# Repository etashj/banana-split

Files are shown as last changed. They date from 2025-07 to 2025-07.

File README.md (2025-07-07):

# banana split
A split, tented keyboard with columnar staggering. Designed from scratch with ergogen, KiCad, and Fusion 360, and fully open-source. 
Runs on 18650 batteries (3.7V 1200 mAh) which provide a mass for tenting. Plan to use a clear acrylic sandwich case which. 
Design will feature clear case, white keys, brown modifiers, and yellow home "row" for a banana split. 40 keys with 4 layer cusotmizable layout. 
Uses 2 nice!nano and nice!view boards which show status. 

Making this because there arent really many ergonomic, but compact keybaord for large hand (almost oxymoronic) which also feature mechanical switches. 

More Photos/CAD model coming soon :/
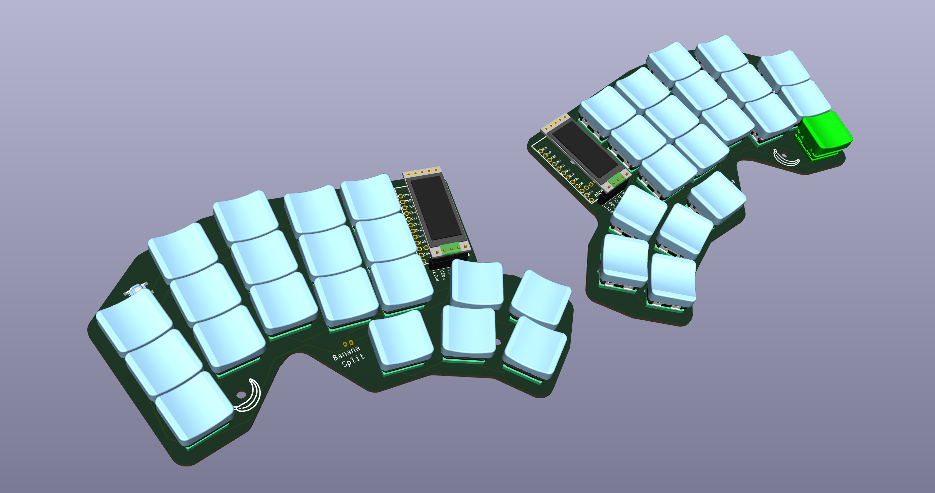
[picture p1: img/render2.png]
render 2


### Case & Keycaps
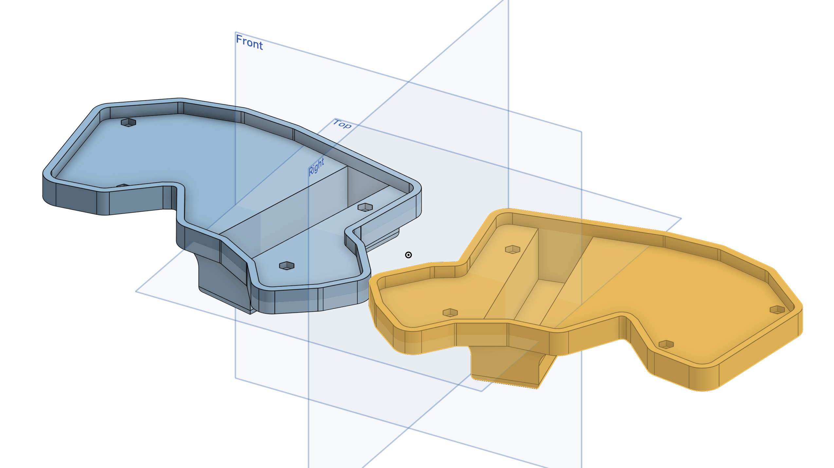
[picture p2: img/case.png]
case

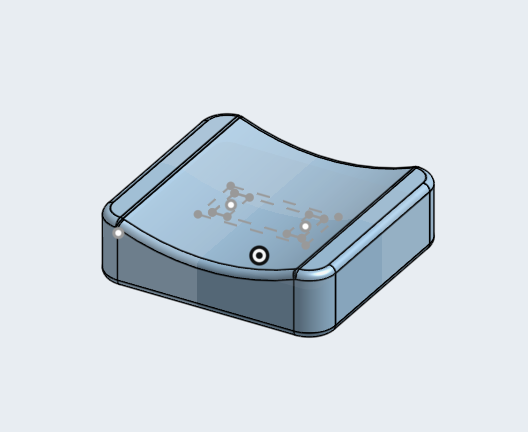
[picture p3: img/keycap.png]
keycap

### PCB
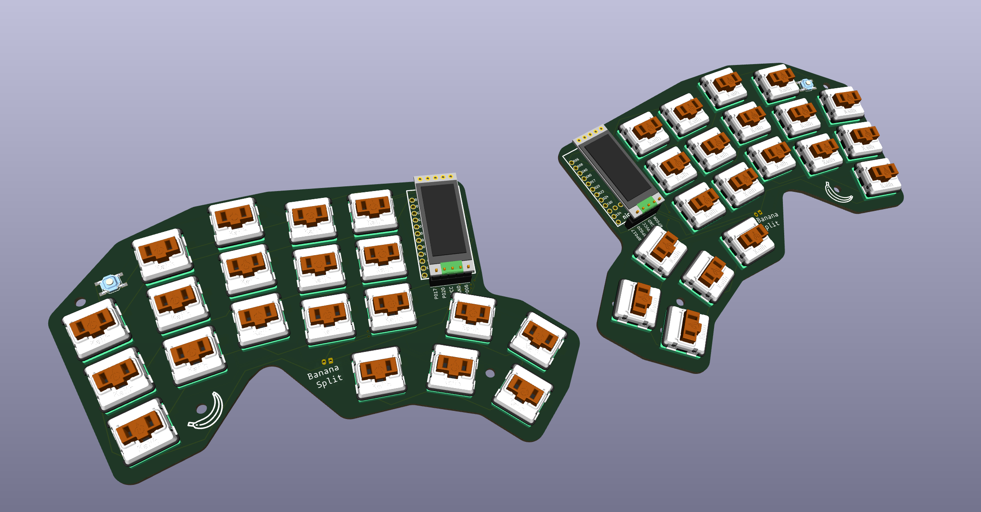
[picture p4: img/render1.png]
render 1 july 7

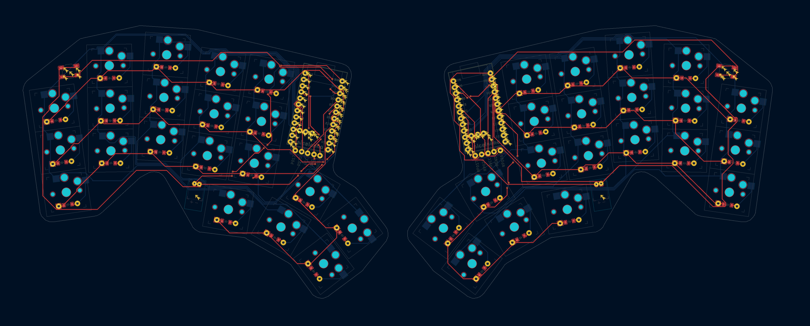
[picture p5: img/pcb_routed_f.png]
PCB Routed Front

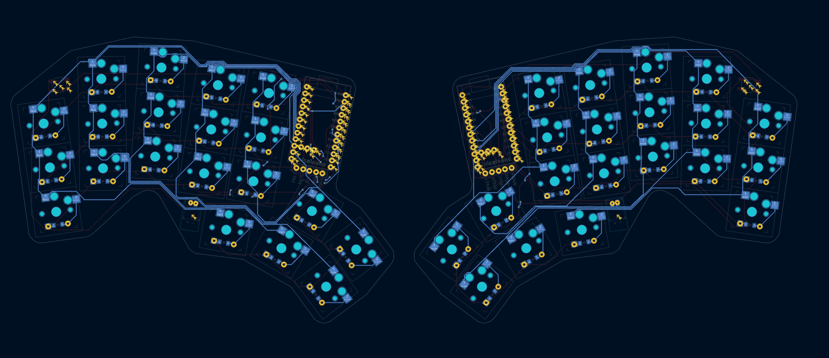
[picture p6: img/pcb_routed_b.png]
PCB Routed Back

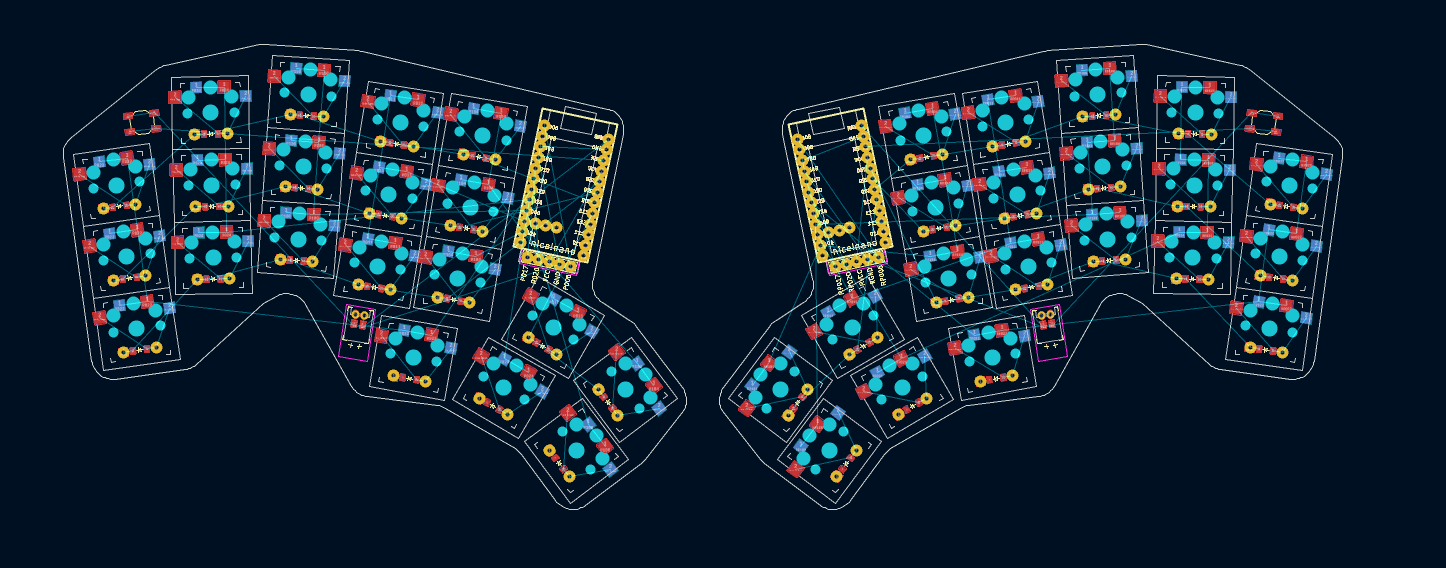
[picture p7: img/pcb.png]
PCB

### ErgoPad Layout
[Design your own at this link](https://pashutk.com/ergopad/)
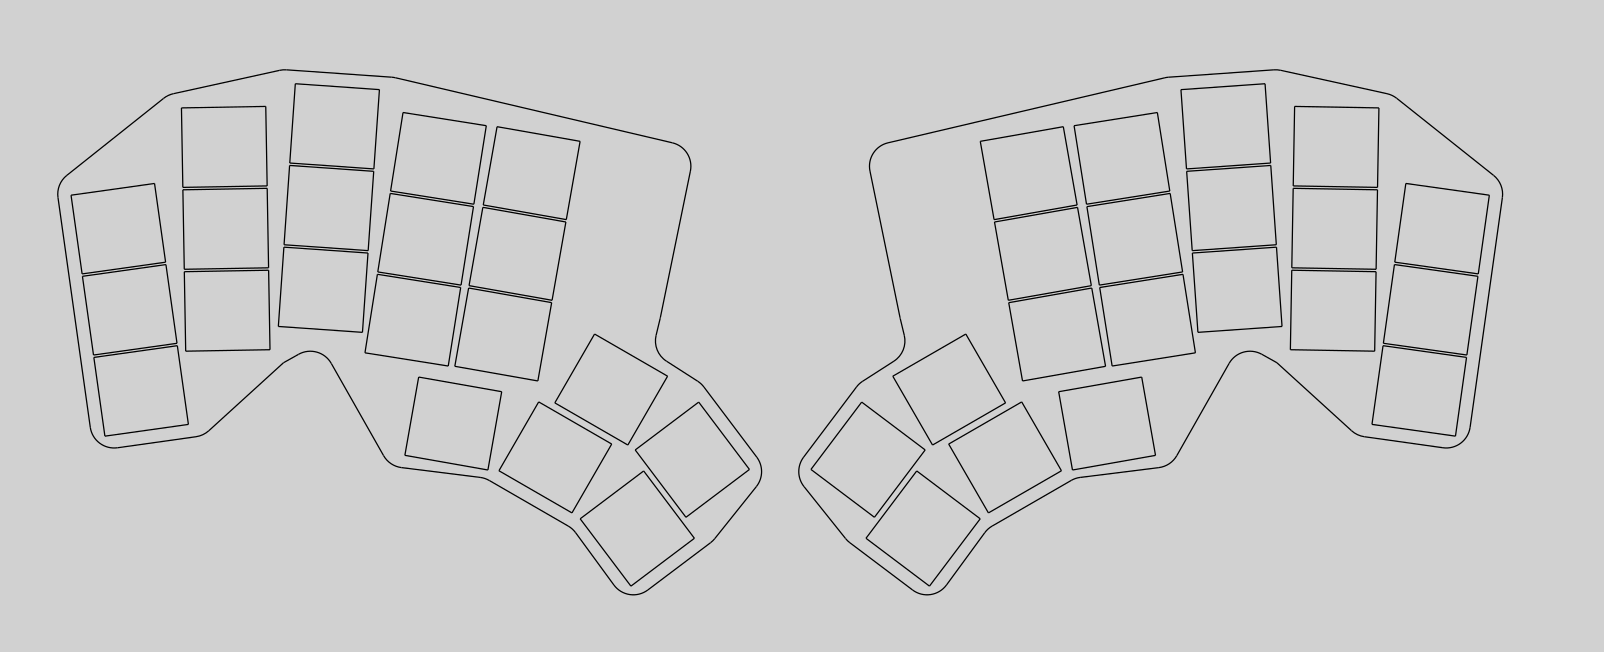
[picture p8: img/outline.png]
Ergopad w/ Outline


Features: 
 - Low profile mechanical switches
 - Low profile sculpted keycaps
 - Wireless! Uses 2 nice!nano (I think)
 - Small display for status info and idle image (2 nice!view)
 - Small/durable 3D printed case
 - Hot swappable switches
 - Reaosnably large battery
 - Easy to switch between the onboard MBP keyboard and good macOS compatibility. (this is a layout consderation). 
 - Small-ish/Portable (Ideally msaller than a handheld console like the Swithc so the case can be used)
 - Customaized for my (larger) hands
 - Fewer keycaps (less movement)

 ### Bill of Materials

| Part Name | Source | Qt | Unit Price | Price | Note |
|-----|-----|---|---|---|---|
|PCB|JLCPCB|5|3.28|16.4|min 5|
|Clear Case|JLC3DP|1|30.64|30.64||
|Keycaps|JLC3DP|40|0.3|12||
|Nice!Nano|[Typeractive](https://typeractive.xyz/products/nice-nano)|2|25|50||
|Nice!View|[Typeractive](https://typeractive.xyz/products/nice-view)|2|20|40||
|Twilight Silent Kalih Choc V1|[BeeKeeb](https://shop.beekeeb.com/product/kailh-silent-switch-linear-twilight/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)|40|1.05|42||
|Choc V1 HotSwap Sockets 100pc |[AliExpress](https://www.aliexpress.us/item/3256808288570508.html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)|1|7.40|7.40|Best price is at 100 pc|
|M3 Screw and Nut Set|[AliExpress](https://www.aliexpress.us/item/3256807407760967.html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)|1|3.94|3.94||
|Rubber Feet 4pk|[AliExpress](https://www.aliexpress.us/item/3256809073816688.html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,scm-url:1007.40050.354490.0,pvid:52a5a5e8-bf4b-41b6-8108-8eef565778c2,tpp_buckets:668%232846%238111%231996&pdp_ext_f=%7B%22order%22%3A%221%22%2C%22eval%22%3A%221%22%2C%22sceneId%22%3A%2230050%22%7D&pdp_npi=4%40dis%21USD%210.91%210.73%21%21%210.91%210.73%21%402103244817519174567381591e3a81%2112000048590082109%21rec%21US%21%21ABX&utparam-url=scene%3ApcDetailTopMoreOtherSeller%7Cquery_from%3A)|2|0.91|1.82||
|18650 Battery Holder|[AliExpress](https://www.aliexpress.us/item/3256802855487110.html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)|2|1.16|2.32||
|18650 Cell|[LIION Wholesale](https://liionwholesale.com/products/vapcell-k25-18650-20a-35a-flat-top-2500mah-battery-genuine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)|2|3.49|6.98||
|Surface Mount Push Switch|[SparkFun](https://liionwholesale.com/products/vapcell-k25-18650-20a-35a-flat-top-2500mah-battery-genuine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)|2|1.05|2.1||

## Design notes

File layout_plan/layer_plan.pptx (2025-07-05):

## Home Layer

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
enter

n

?
/

Ctrl

Shift

Cmd

BackSp

Space

Opt

Symbols

Num + Nav

When pressed together forms Funcs

## Num + Nav Layer

7

8

9

null

null

home

Left

backsp

Up

End

Right
→

del

esc

4

5

6

null

null

Down

PgUp

null

1

2

null

enter

null

0

3

Tab

enter

null

PgDn

Ctrl

Shift

Cmd

BackSp

Space

Opt

Symbols

Num + Nav

When pressed together forms Funcs

## Symbol Layer

%

$

null

null

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
enter

*

?

Ctrl

Shift

Cmd

BackSp

Space

Opt

Symbols

Num + Nav

When pressed together forms Funcs

## Func Layer

F7

F8

F9

null

null

Br-

Br+

Screenshot

F10

F4

F5

F6

null

null

<<

pause

>>

Emoji Panel

F11

F1

F2

F3

null

null

Vol-

Mute

Vol+

null

F12

Tab

enter

Lock Device

Ctrl

Shift

Cmd

BackSp

Space

Opt

Symbols

Num + Nav

When pressed together forms Funcs

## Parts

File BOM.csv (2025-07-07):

Banana Split Bill of Materials
 | Part Name | Source (linked) | Quantity | Unit Price | Price | Notes
Manufactured Parts
 | PCB | JLCPCB | 5 | $3.28 | $16.40 | Minimum 5 Produced
 | Clear Case | JLC3DP | 1 | $30.64 | $30.64
Keycaps | Translucent Keycaps | JLC3DP | 22 | $0.30 | $6.60
 | Translucent Yellow Keycaps | JLC3DP | 10 | $0.30 | $3.00
 | Translucent Brown Keycaps | JLC3DP | 8 | $0.30 | $2.40
Purchased Components
 | Nice!Nano | Typeractive | 2 | $25.00 | $50.00
 | Nice!View | Typeractive | 2 | $20.00 | $40.00
 | 18650 Battery Holder | AliExpress | 2 | $1.16 | $2.32
 | 18650 Battery (VAPCELL K25 18650) | LIION Wholesale | 2 | $3.49 | $6.98
 | Twilight Silent Kalih Choc V1 Switches | BeeKeeb | 40 | $1.05 | $42.00
 | Choc V1 Hot Swap Sockets (100 pc) | AliExpress | 1 | $7.40 | $7.40 | Best price has 100 pc, only use 40.
 | Surface Mount Push Switch (SW_TACT_ALPS_SKQGABE010) | Sparkfun | 2 | $1.05 | $2.10
 | M3 Screw and Nut Set | AliExpress | 1 | $3.94 | $3.94
 | Rubber Feet (4 pack) | AliExpress | 2 | $0.91 | $1.82
SUBTOTAL |  |  |  |  | $215.60
Shipping Estimate |  |  |  |  | $20.00
Projected 7% Tax |  |  |  |  | $16.49
TOTAL |  |  |  |  | $252.09

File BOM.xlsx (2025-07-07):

Banana Split Bill of Materials
 | Part Name | Source (linked) | Quantity | Unit Price | Price | Notes
Manufactured Parts
 | PCB | JLCPCB | 5 | $3.28 | $16.40 | Minimum 5 Produced
 | Clear Case | JLC3DP | 1 | $30.64 | $30.64
Keycaps | Translucent Keycaps | JLC3DP | 22 | $0.30 | $6.60
 | Translucent Yellow Keycaps | JLC3DP | 10 | $0.30 | $3.00
 | Translucent Brown Keycaps | JLC3DP | 8 | $0.30 | $2.40
Purchased Components
 | Nice!Nano | Typeractive (https://typeractive.xyz/products/nice-nano) | 2 | $25.00 | $50.00
 | Nice!View | Typeractive (https://typeractive.xyz/products/nice-view) | 2 | $20.00 | $40.00
 | 18650 Battery Holder | AliExpress (https://www.aliexpress.us/item/3256802855487110.html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) | 2 | $1.16 | $2.32
 | 18650 Battery (VAPCELL K25 18650) | LIION Wholesale (https://liionwholesale.com/products/vapcell-k25-18650-20a-35a-flat-top-2500mah-battery-genuine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) | 2 | $3.49 | $6.98
 | Twilight Silent Kalih Choc V1 Switches | BeeKeeb (https://shop.beekeeb.com/product/kailh-silent-switch-linear-twilight/) | 40 | $1.05 | $42.00
 | Choc V1 Hot Swap Sockets (100 pc) | AliExpress (https://www.aliexpress.us/item/3256808288570508.html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) | 1 | $7.40 | $7.40 | Best price has 100 pc, only use 40.
 | Surface Mount Push Switch (SW_TACT_ALPS_SKQGABE010) | Sparkfun (https://www.sparkfun.com/mini-pushbutton-switch-smd.html) | 2 | $1.05 | $2.10
 | M3 Screw and Nut Set | AliExpress (https://www.aliexpress.us/item/3256807407760967.html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) | 1 | $3.94 | $3.94
 | Rubber Feet (4 pack) | AliExpress (https://www.aliexpress.us/item/3256809073816688.html?scm_id=1007.40050.354490.0&scm-url=1007.40050.354490.0) | 2 | $0.91 | $1.82
SUBTOTAL |  |  |  |  | $215.60
Shipping Estimate |  |  |  |  | $20.00
Projected 7% Tax |  |  |  |  | $16.49
TOTAL |  |  |  |  | $252.09

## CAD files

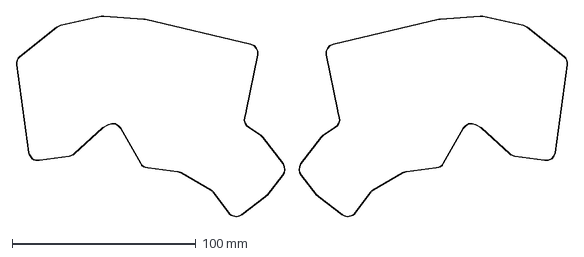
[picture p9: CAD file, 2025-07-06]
ergogen-out/outlines/board_full.dxf
300.3 x 109.1 mm

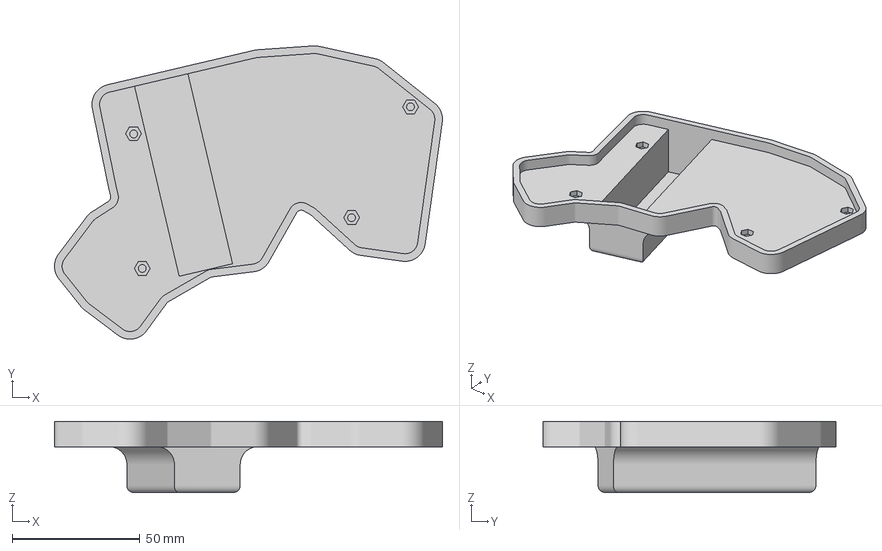
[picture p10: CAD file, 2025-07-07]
case_files/Case-Right.3mf
152.1 x 115.0 x 28.0 mm

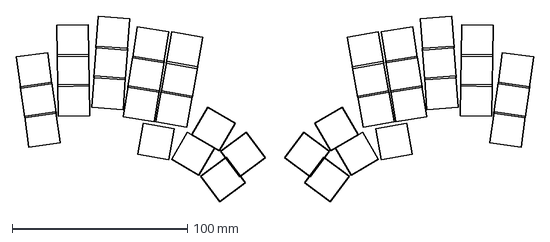
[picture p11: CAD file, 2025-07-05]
ergogen-out/points/demo.dxf
295.1 x 105.7 mm

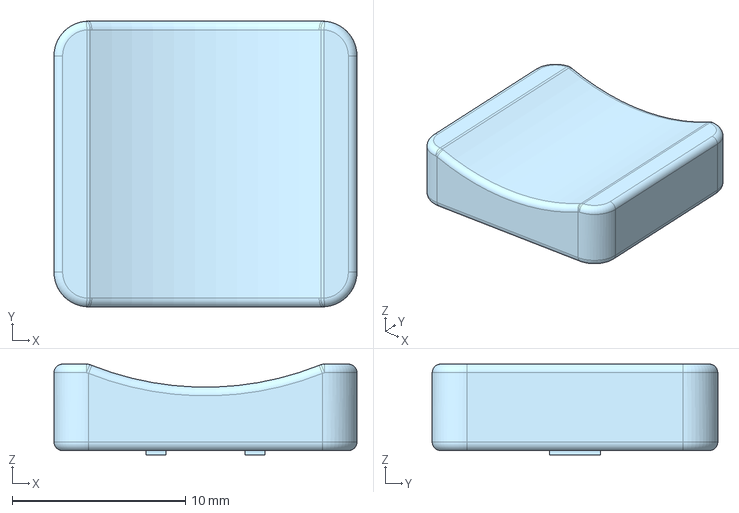
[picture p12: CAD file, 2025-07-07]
models/keycap.step
17.5 x 16.5 x 5.25 mm

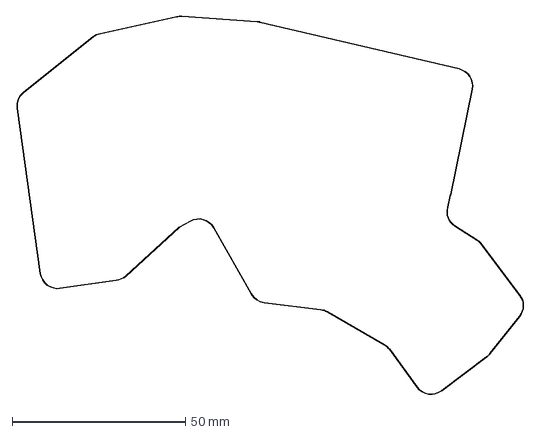
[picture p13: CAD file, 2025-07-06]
ergogen-out/outlines/board_left.dxf
146.6 x 109.1 mm

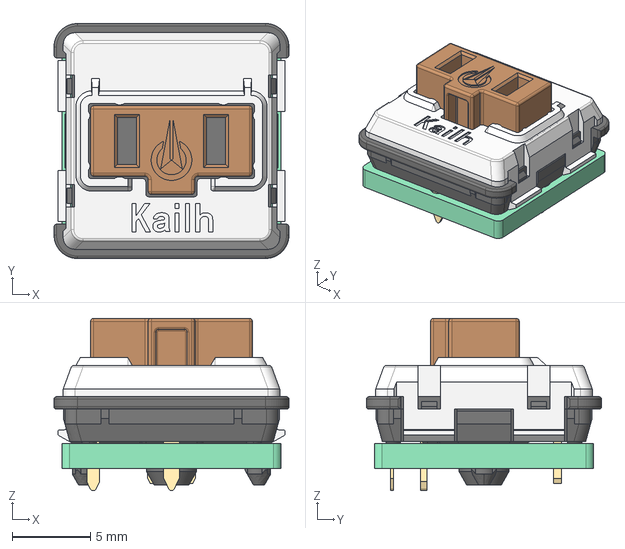
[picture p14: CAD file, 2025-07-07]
models/Kailh_Choc_Low_Profile_Switch.step
15.0 x 15.0 x 11.0 mm

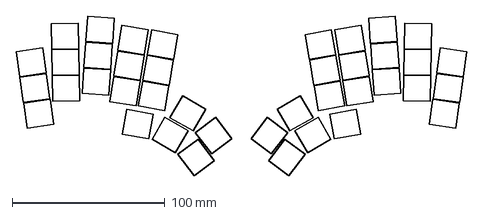
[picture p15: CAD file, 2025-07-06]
ergogen-out/outlines/keys.dxf
294.4 x 104.3 mm

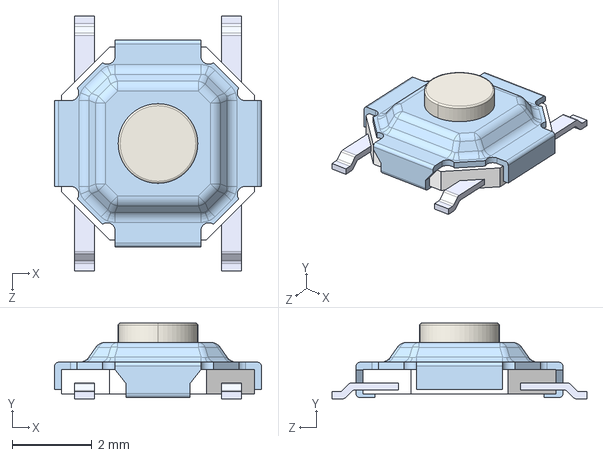
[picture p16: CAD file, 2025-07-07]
models/reset.step
5.20 x 1.90 x 6.40 mm

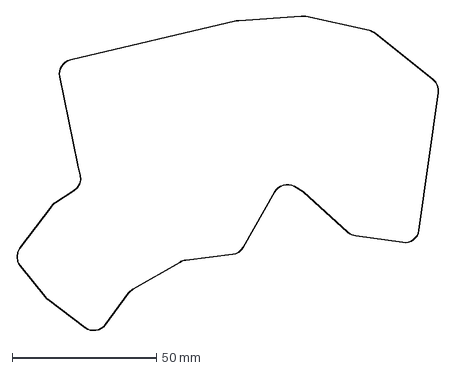
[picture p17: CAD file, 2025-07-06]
ergogen-out/outlines/board_right.dxf
146.6 x 109.1 mm

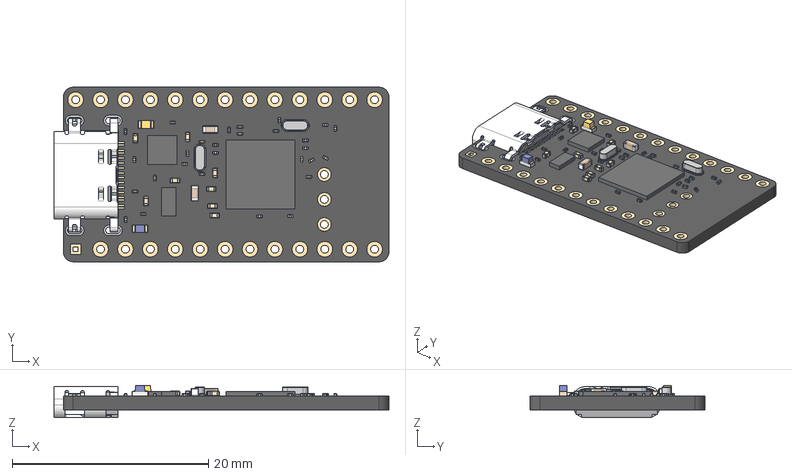
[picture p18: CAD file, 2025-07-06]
models/nicenano.step
34.2 x 17.8 x 3.28 mm
nice!nano v1.0
SSOP16
LED_0603_1608Metric_ON
LED_0603_1608Metric_ON_1
Crystal Oscillator
Crystal Oscillator_1
usb4520-03-0-a_1
C0201 x 21
C0402 x 8
C0201_1 x 7

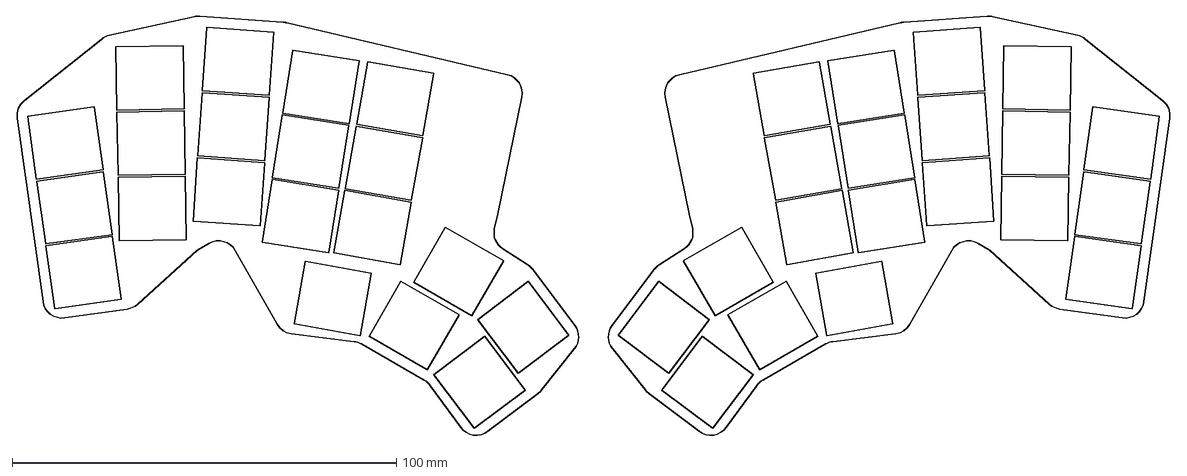
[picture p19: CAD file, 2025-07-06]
ergogen-out/outlines/combo.dxf
300.3 x 109.1 mm

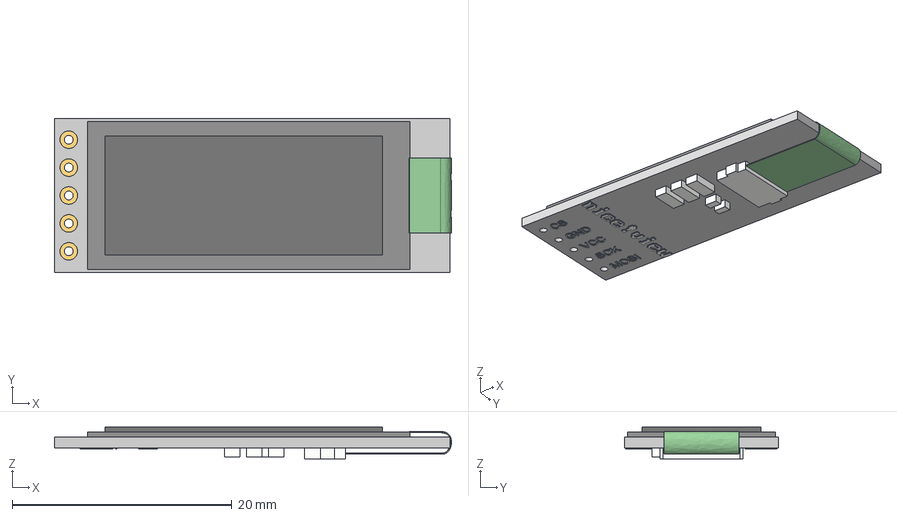
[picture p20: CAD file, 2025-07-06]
models/niceview.step
36.1 x 14.0 x 2.90 mm

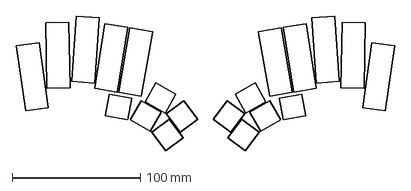
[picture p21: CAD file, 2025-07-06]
ergogen-out/outlines/raw.dxf
294.9 x 104.9 mm

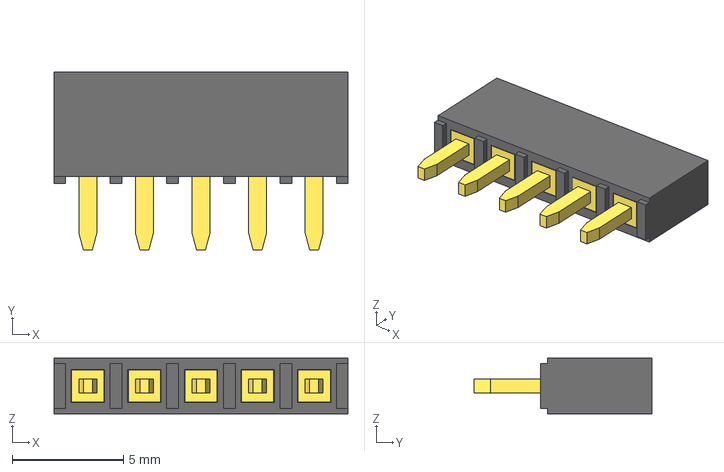
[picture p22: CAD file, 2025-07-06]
models/fem5pin.step
13.2 x 8.00 x 2.50 mm

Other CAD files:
case_files/Case-Left.3mf
models/mal12pin.step
models/jstph.stp
models/mal5pin.step
cad_files/case_cad_file.x_t
cad_files/keycap_cad_file.x_t
keycap.3mf
models/fem12pin.step

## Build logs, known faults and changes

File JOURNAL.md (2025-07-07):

---
title: "Banana Split"
author: "Etash Jhanji"
description: "A split, hot swappable, columnar staggered, wireless keyboard custom themed and custom designed for my hand shape and use in programming."
date: 2025-06-03
---
**Total time: ~16 hr**
---

## July 3rd [2025-06-03]
**~3 hrs**

Idea was conceptualized today and most of the engineering goals were set. theyre also decribed in the readme

engineering goals: 
- low profile
- split, column stagger; perfectly ergonomic for my habds
- wireless (bluetooth) and thus battery powered
- silent for use in shared spaces
- USB C charger
- OLED starys screen for modes and stats
- sculpted and colored keycaps (no text)
- retro techy look: lots of clear plastic (resin printing?)

I also decided on the following tools: 
- Ergopad: finger spacing and splay
- Ergogen: key placement, pcb, outline, etc
- KiCad: PCB
- inkscape: svg and dxf editing for laser cut
- fusion 360: (optional) 3d modelling

inspiration comes from the following: 
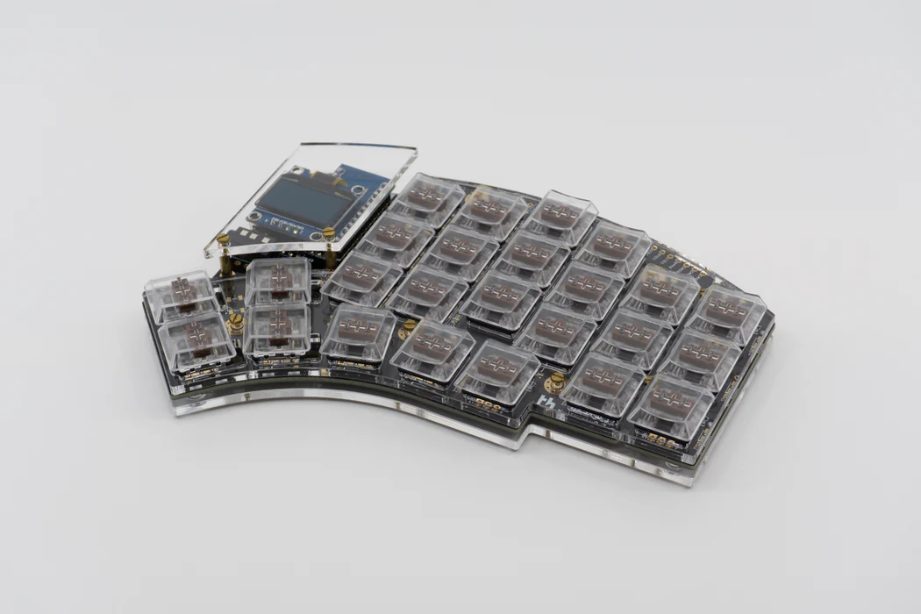
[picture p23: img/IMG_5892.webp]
inspiration photo 1

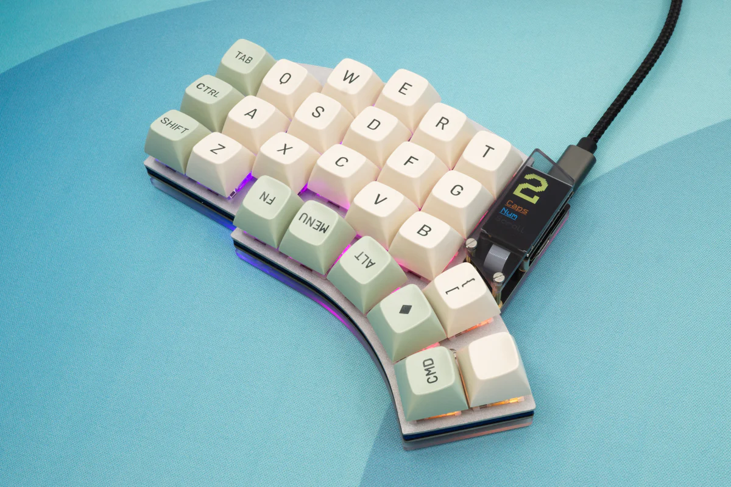
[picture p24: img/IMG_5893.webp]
inspiration photo 2

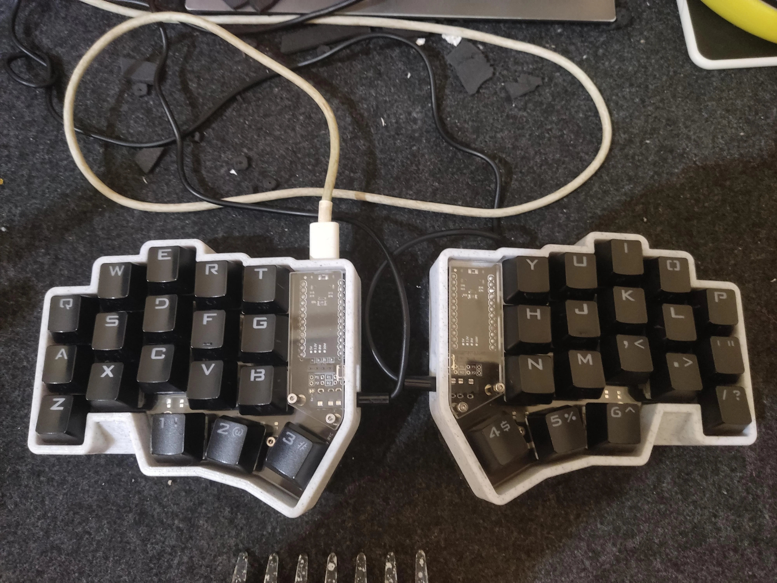
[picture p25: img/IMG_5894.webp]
inspiration photo 3

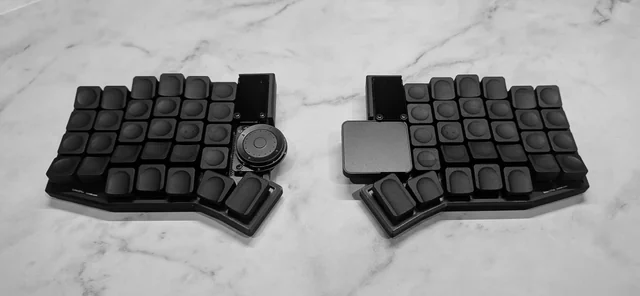
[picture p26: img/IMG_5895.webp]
inspiration photo 4

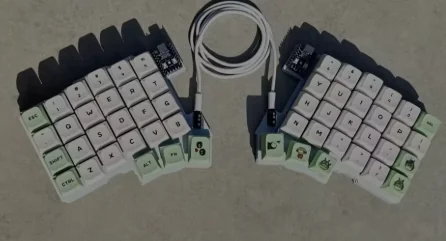
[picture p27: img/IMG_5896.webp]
inspiration photo 5


## July 4th [2025-06-04]
**~0.5 hr**

Happy 4th of July! Not much got done today, laid out stagger and splay in ergopad. see below. 

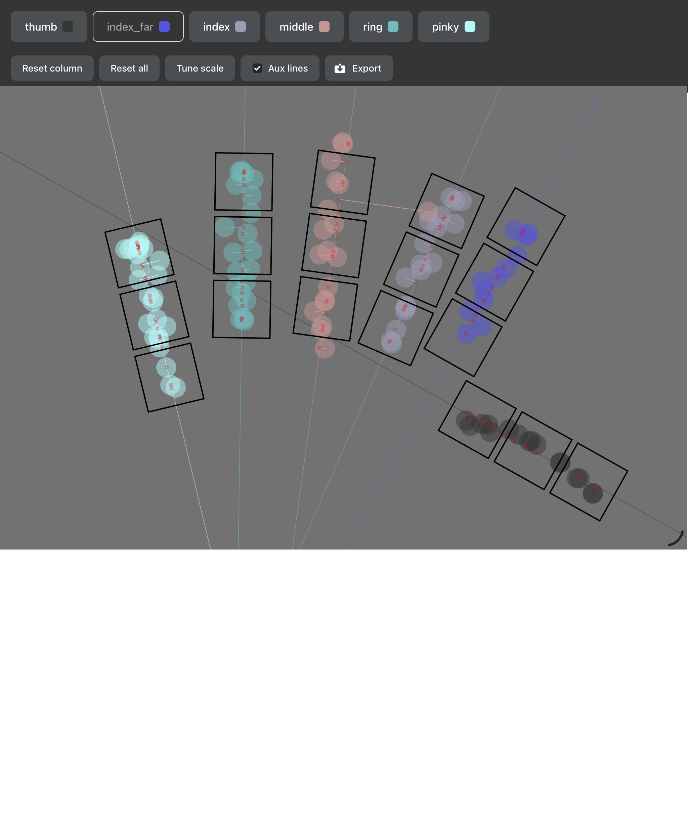
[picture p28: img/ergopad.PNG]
ergopad

firework

## July 5th [2025-06-05]
**~1.5 hrs**

Learned a lot of ergogen's point syntax (using documentation :/) and laid out the full set of keys. Forty keys witha thimb cluster and a very basic preview. 
The syntax is pretty intuitive and its very good for explicityly declaring relative positioning. 
Considering a Miryoki inspirated layer layout, but im not sure how to code with only 40 keys. 

found FlatFootFox's tutorial to lay out an outline as well for the board. 

ergogen

## July 6th [2025-06-06]
**~5 hrs**

FlatFootFox's tutorial now has goat status. I was able to layout the full PCB with footprints and link contacts for KiCad. Spent a few more hours routing the board. Its a little messy but uotimately effective. Thanks to the pathfinder ysws for teaching me kicad. 
Going to add some nice groahics on the sikscreen and start considering cases. 
i wanted clear casing, so cutting clear acrylic may work but itll be aurd to achieve the tent. If i want to use 18650 cells it also requies additonal modelling wotk to make the round suape and requires 3d printing. Maybe its time to hop back in fusion 360 and design the bottom of the case out of clear plastic for 3D printing. Top still should be clear acrylic hopefully and similar translucence for the keycaps. 
This means I have to consider adding mounting holes and also checking how the 18650 will get the right connector. 

routed pcb front
routed pcb back
pcb

## July 7th [2025-06-07]
**~6 hrs**

Working on the PCB more. Adding 3d models for switches and buttons as well as for the nicenano and display. New decisions about the case: no top plate. CLear resin printing to make a bowl of sorts for the bottom and then use screws to mount the board to said bowl. This simplifies the case and manufacturing, saves money while achiving the same techy look. 

Also finished the case. It's designed to accommodate and 18650 which becomes tent and allows the board to be mounted via M3 screws. See below for the case. I was going to use Fusion 360, but OnShape had a Wakatime plugin, but I also couldn't get it to work. 

case

Went for a relatively simple keycap saddle design for easy movement of fingers. Also desinged in onshape. 
keycap

render 2

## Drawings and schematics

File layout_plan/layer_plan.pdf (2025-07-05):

# Home Layer

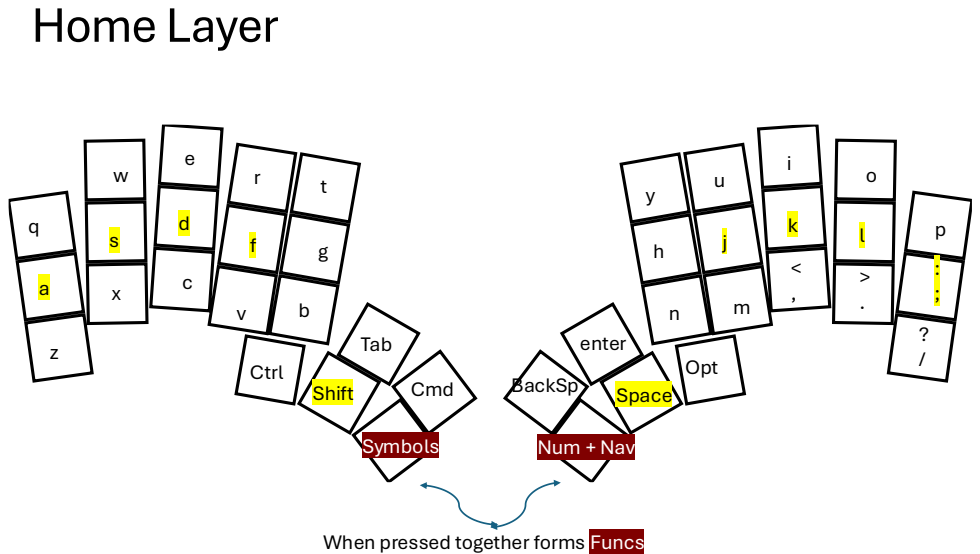
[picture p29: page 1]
Shift; Space; Ctrl; Cmd; BackSp; Opt; Tab; enter; Symbols; Num + Nav

When pressed together forms Funcs

# Num + Nav Layer

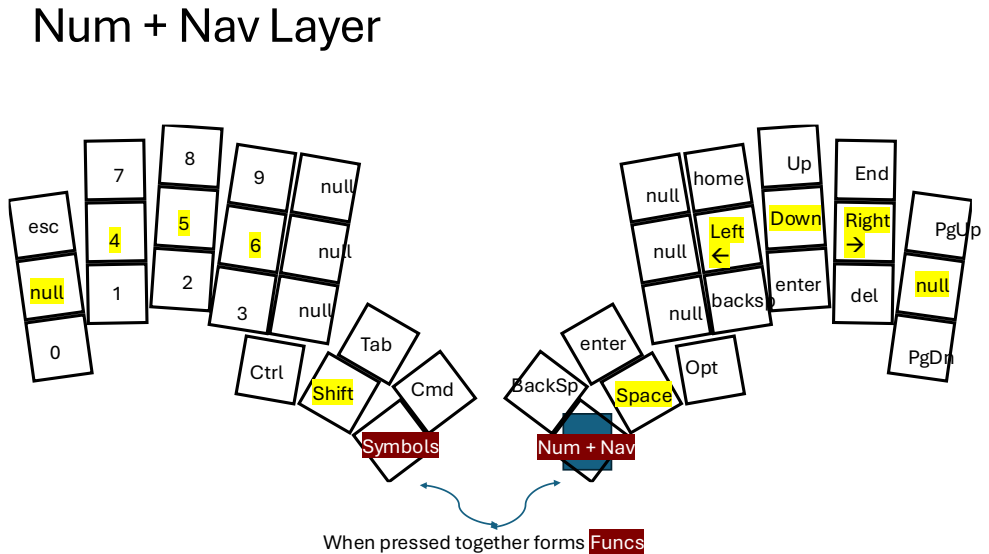
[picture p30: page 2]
esc; null; home; End; PgUp; Left; Down; Right; null backsp; enter del; Shift; Space; Ctrl; Cmd; BackSp; Opt; Tab; enter; Symbols; Num + Nav; PgDn

# Symbol Layer

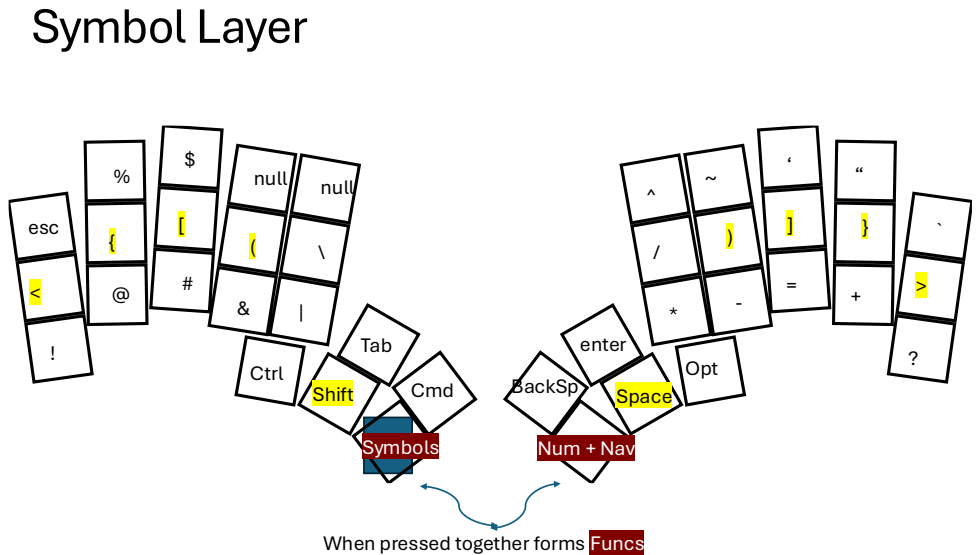
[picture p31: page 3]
esc; null; Shift; Space; Ctrl; Cmd; BackSp; Opt; Tab; enter; Symbols; Num + Nav

# Func Layer

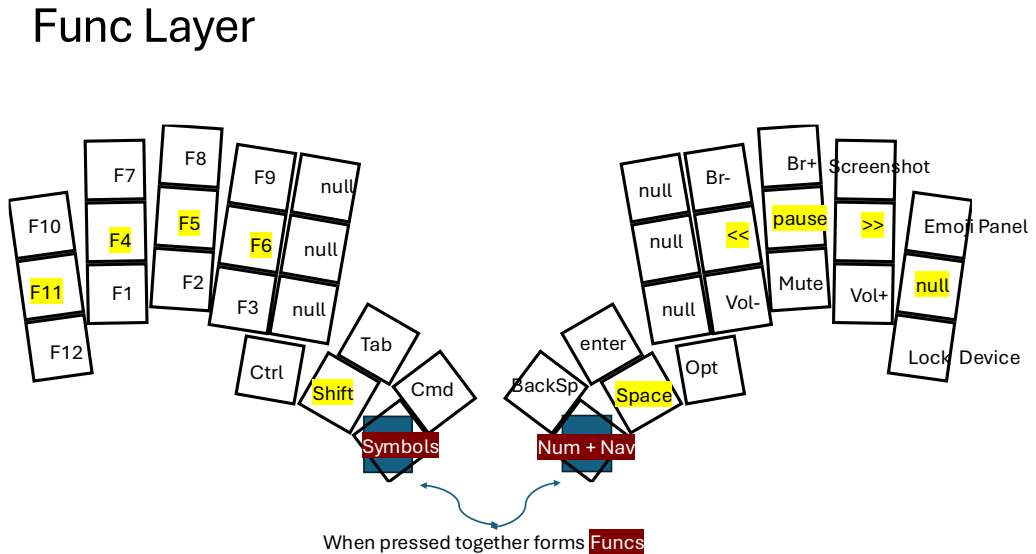
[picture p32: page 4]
null; Br+ Screenshot; Emoji Panel; pause; Vol-; Mute Vol+; Shift; Space; Ctrl; Cmd; BackSp; Opt; Tab; enter; Symbols; Num + Nav; Lock Device

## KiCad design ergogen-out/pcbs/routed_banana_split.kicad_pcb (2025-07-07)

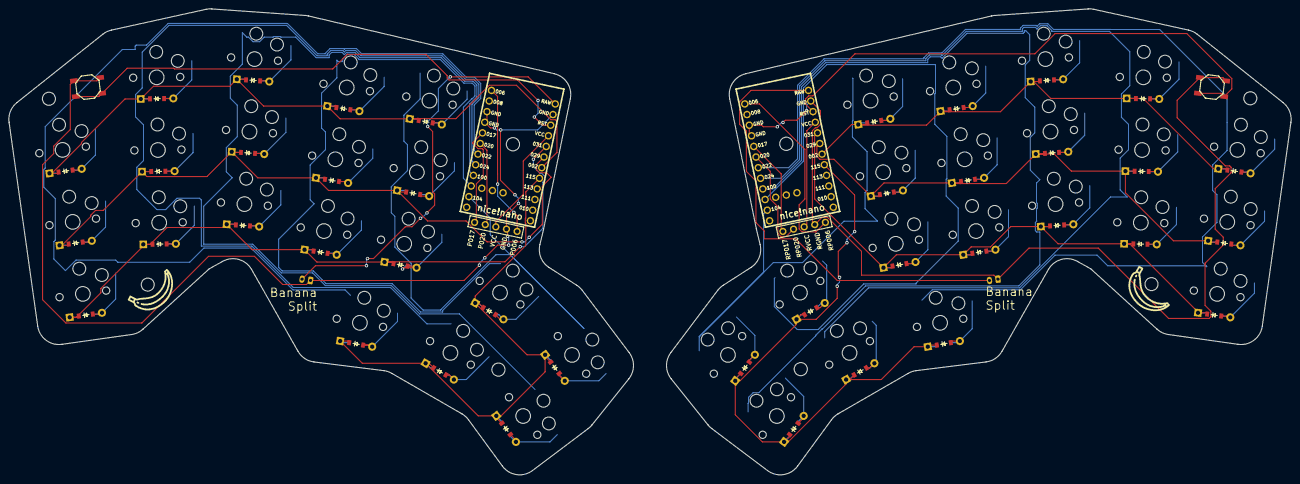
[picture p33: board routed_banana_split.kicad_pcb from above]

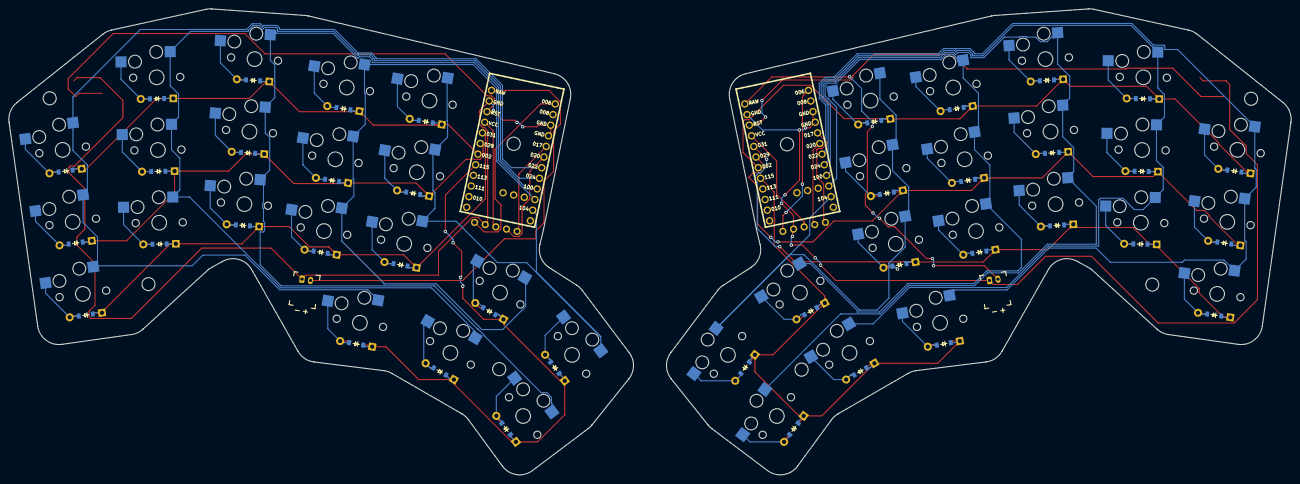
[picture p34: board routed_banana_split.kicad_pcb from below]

Board: 2 copper layers, 299.9 x 109.0 mm, 88 parts (2 on the bottom side), 72 nets.

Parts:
B1, B2: SW_TACT_ALPS_SKQGABE010
D1, D2, D3, D4, D5, D6, D7, D8, D9, D10, D11, D12, D13, D14, D15, D16, D17, D18, D19, D20, D21, D22, D23, D24, D25, D26, D27, D28, D29, D30, D31, D32, D33, D34, D35, D36, D37, D38, D39, D40: ComboDiode
DISP1, DISP2: display_nice_view
JST1, JST2: battery_connector_jst_ph_2
MCU1, MCU2: nice_nano
S1, S2, S3, S4, S5, S6, S7, S8, S9, S10, S11, S12, S13, S14, S15, S16, S17, S18, S19, S20, S21, S22, S23, S24, S25, S26, S27, S28, S29, S30, S31, S32, S33, S34, S35, S36, S37, S38, S39, S40: PG1350

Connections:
GND: B1.1, DISP1.4, JST1.1, MCU1.3, MCU1.4, MCU1.23
P002: D3.1, D6.1, D9.1, D12.1, D15.1, MCU1.18
P006: DISP1.5, MCU1.1
P011: MCU1.10, S10.1, S11.1, S12.1, S19.1
P017: DISP1.1, MCU1.5
P020: DISP1.2, MCU1.6
P022: MCU1.7, S1.1, S2.1, S3.1, S16.1
P024: MCU1.8, S4.1, S5.1, S6.1, S17.1
P029: D2.1, D5.1, D8.1, D11.1, D14.1, MCU1.19
P031: D1.1, D4.1, D7.1, D10.1, D13.1, MCU1.20
P100: MCU1.9, S7.1, S8.1, S9.1, S18.1
P104: MCU1.11, S13.1, S14.1, S15.1, S20.1
P115: D16.1, D17.1, D18.1, D19.1, D20.1, MCU1.17
RAW: JST1.2, MCU1.24
RGND: B2.1, DISP2.4, JST2.1, MCU2.3, MCU2.4, MCU2.23
RP002: D23.1, D26.1, D29.1, D32.1, D35.1, MCU2.18
RP006: DISP2.5, MCU2.1
RP011: MCU2.10, S30.1, S31.1, S32.1, S39.1
RP017: DISP2.1, MCU2.5
RP020: DISP2.2, MCU2.6
RP022: MCU2.7, S21.1, S22.1, S23.1, S36.1
RP024: MCU2.8, S24.1, S25.1, S26.1, S37.1
RP029: D22.1, D25.1, D28.1, D31.1, D34.1, MCU2.19
RP031: D21.1, D24.1, D27.1, D30.1, D33.1, MCU2.20
RP100: MCU2.9, S27.1, S28.1, S29.1, S38.1
RP104: MCU2.11, S33.1, S34.1, S35.1, S40.1
RP115: D36.1, D37.1, D38.1, D39.1, D40.1, MCU2.17
RRAW: JST2.2, MCU2.24
RRST: B2.2, MCU2.22
RST: B1.2, MCU1.22
RVCC: DISP2.3, MCU2.21
VCC: DISP1.3, MCU1.21
home_thumb: D17.2, S17.2
in_default: D19.2, S19.2
in_thumb: D16.2, S16.2
index_bottom: D10.2, S10.2
index_home: D11.2, S11.2
index_top: D12.2, S12.2
indexfar_bottom: D13.2, S13.2
indexfar_home: D14.2, S14.2
indexfar_top: D15.2, S15.2
middle_bottom: D7.2, S7.2
middle_home: D8.2, S8.2
middle_top: D9.2, S9.2
mirror_home_thumb: D37.2, S37.2
mirror_in_default: D39.2, S39.2
mirror_in_thumb: D36.2, S36.2
mirror_index_bottom: D30.2, S30.2
mirror_index_home: D31.2, S31.2
mirror_index_top: D32.2, S32.2
mirror_indexfar_bottom: D33.2, S33.2
mirror_indexfar_home: D34.2, S34.2
mirror_indexfar_top: D35.2, S35.2
mirror_middle_bottom: D27.2, S27.2
mirror_middle_home: D28.2, S28.2
mirror_middle_top: D29.2, S29.2
mirror_out_default: D40.2, S40.2
mirror_out_thumb: D38.2, S38.2
mirror_pinky_bottom: D21.2, S21.2
mirror_pinky_home: D22.2, S22.2
mirror_pinky_top: D23.2, S23.2
mirror_ring_bottom: D24.2, S24.2
mirror_ring_home: D25.2, S25.2
mirror_ring_top: D26.2, S26.2
out_default: D20.2, S20.2
out_thumb: D18.2, S18.2
pinky_bottom: D1.2, S1.2
pinky_home: D2.2, S2.2
pinky_top: D3.2, S3.2
ring_bottom: D4.2, S4.2
ring_home: D5.2, S5.2
ring_top: D6.2, S6.2

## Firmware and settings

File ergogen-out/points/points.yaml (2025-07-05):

leftmain_pinky_bottom:
    x: 1.892957899999999
    'y': 2.9294410000000006
    r: 8
    meta:
        stagger: 0
        spread: 19
        splay: 8
        origin:
            - -20
            - 15
        orient: 0
        shift:
            - 0
            - 0
        rotate: 0
        adjust: {}
        width: 18
        height: 18
        padding: 17
        autobind: 10
        skip: false
        asym: both
        colrow: pinky_bottom
        name: leftmain_pinky_bottom
        zone:
            columns:
                pinky:
                    key:
                        splay: 8
                        origin:
                            - -20
                            - 15
                    rows: {}
                    name: pinky
                ring:
                    key:
                        stagger: 14
                        splay: -7
                        spread: cx + 2
                    rows: {}
                    name: ring
                middle:
                    key:
                        splay: -5
                        spread: cx+2
                        stagger: 4
                    rows: {}
                    name: middle
                index:
                    key:
                        splay: -5
                        stagger: -5
                        spread: cx+1
                    rows: {}
                    name: index
                indexfar:
                    key:
                        splay: -1
                        stagger: 0
                    rows: {}
                    name: indexfar
            rows:
                bottom: {}
                home: {}
                top: {}
            name: leftmain
        col:
            key:
                splay: 8
                origin:
                    - -20
                    - 15
            rows: {}
            name: pinky
        row: bottom
        mirrored: false
        bind:
            - 10
            - 0
            - 0
            - 0
leftmain_pinky_home:
    x: -0.4729848000000012
    'y': 19.7639982
    r: 8
    meta:
        stagger: 0
        spread: 19
        splay: 8
        origin:
            - -20
            - 15
        orient: 0
        shift:
            - 0
            - 0
        rotate: 0
        adjust: {}
        width: 18
        height: 18
        padding: 17
        autobind: 10
        skip: false
        asym: both
        colrow: pinky_home
        name: leftmain_pinky_home
        zone:
            columns:
                pinky:
                    key:
                        splay: 8
                        origin:
                            - -20
                            - 15
                    rows: {}
                    name: pinky
                ring:
                    key:
                        stagger: 14
                        splay: -7
                        spread: cx + 2
                    rows: {}
                    name: ring
                middle:
                    key:
                        splay: -5
                        spread: cx+2
                        stagger: 4
                    rows: {}
                    name: middle
                index:
                    key:
                        splay: -5
                        stagger: -5
                        spread: cx+1
                    rows: {}
                    name: index
                indexfar:
                    key:
                        splay: -1
                        stagger: 0
                    rows: {}
                    name: indexfar
            rows:
                bottom: {}
                home: {}
                top: {}
            name: leftmain
        col:
            key:
                splay: 8
                origin:
                    - -20
                    - 15
            rows: {}
            name: pinky
        row: home
        mirrored: false
        bind:
            - 10
            - 10
            - 10
            - 0
leftmain_pinky_top:
    x: -2.8389275000000014
    'y': 36.598555399999995
    r: 8
    meta:
        stagger: 0
        spread: 19
        splay: 8
        origin:
            - -20
            - 15
        orient: 0
        shift:
            - 0
            - 0
        rotate: 0
        adjust: {}
        width: 18
        height: 18
        padding: 17
        autobind: 10
        skip: false
        asym: both
        colrow: pinky_top
        name: leftmain_pinky_top
        zone:
            columns:
                pinky:
                    key:
                        splay: 8
                        origin:
                            - -20
                            - 15
                    rows: {}
                    name: pinky
                ring:
                    key:
                        stagger: 14
                        splay: -7
                        spread: cx + 2
                    rows: {}
                    name: ring
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

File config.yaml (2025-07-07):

meta:
  version: 0.0.1
  engine: 4.1.0
  author: Etash Jhanji
units:
  $default_padding: cy
  px: cx+5
  py: cy+5
points: 
  zones: 
    leftmain: 
      columns: 
        pinky: 
          key.splay: 8
          key.origin: [-20, 15]
          key.column_net: P022
          key.mirror.column_net: RP022
        ring: 
          key.stagger: 14
          key.splay: -7
          key.spread: cx + 2
          key.column_net: P024
          key.mirror.column_net: RP024
        middle: 
          key.splay: -5
          key.spread: cx+2
          key.stagger: 4
          key.column_net: P100
          key.mirror.column_net: RP100
        index:
          key.splay: -5
          key.stagger: -5
          key.spread: cx+1
          key.column_net: P011
          key.mirror.column_net: RP011
        indexfar:
          key.splay: -1
          key.stagger: 0
          key.column_net: P104
          key.mirror.column_net: RP104
      rows: 
        bottom:
          row_net: P031
          mirror.row_net: RP031
        home:
          row_net: P029
          mirror.row_net: RP029
        top:
          row_net: P002
          mirror.row_net: RP002
      anchor: 
        shift: [85, -150]
    leftthumb: 
      anchor: 
        ref: leftmain_indexfar_bottom
        shift: [-7, -20]
      columns:
        in: 
          key.column_net: P022
          key.mirror.column_net: RP022
        home: 
          key.splay: -20
          key.shift: [4, -2]
          key.column_net: P024
          key.mirror.column_net: RP024
        out: 
          key.splay: -23
          key.shift: [9, -3]
          key.column_net: P100
          key.mirror.column_net: RP100
      rows: 
        thumb: 
          key.splay: 6
      key: 
        row_net: P115
        mirror.row_net: RP115
    leftthumbfar: 
      anchor: 
        ref: leftthumb_home_thumb
      columns: 
        in: 
          key.column_net: P011
          key.mirror.column_net: RP011
        out: 
          key.splay: -23
          key.shift: [0, cy-2]
          key.column_net: P104
          key.mirror.column_net: RP104
      key: 
        shift: [3, cy+1]
        row_net: P115
        mirror.row_net: RP115
  mirror: &mirror
    ref: leftmain_pinky_home
    distance: 270
outlines: 
  raw: 
    - what: rectangle
      where: true
      size: [cx, cy]
  keys: 
    - what: rectangle
      where: true
      size: [cx-0.5, cy-0.5]
  board_left: 
    - what: polygon
      operation: stack
      points: 
        - ref: leftmain_pinky_top
          shift: [-0.5px,0.5py]
        - ref: leftmain_ring_top
          shift: [-0.5px,0.5py]
        - ref: leftmain_middle_top
          shift: [-0.5px,0.5py]
        - ref: leftmain_middle_top
          shift: [0.5px,0.5py]
        #- ref: leftmain_index_top
        #  shift: [0.5px,0.5py]
        - ref: leftmain_indexfar_top
          shift: [0.5px + 21,0.5py]
        - ref: leftmain_indexfar_top
          shift: [0.5px + 20,0.5py-36]
        - ref: leftthumbfar_in
          shift: [0.15px,0.5py]
        - ref: leftthumbfar_out
          shift: [-0.5px,0.5py]
        - ref: leftthumbfar_out
          shift: [0.5px,0.5py]
        - ref: leftthumb_out_thumb
          shift: [0.5px,0.5py]
        - ref: leftthumb_out_thumb
          shift: [0.5px,-0.5py]
        #- ref: leftthumb_out_thumb
        #  shift: [-0.5px,-0.5py]
        - ref: leftthumb_home_thumb
          shift: [0.5px-1,-0.5py]
        - ref: leftthumb_home_thumb
          shift: [-0.5px+1,-0.5py]
        - ref: leftthumb_in_thumb
          shift: [-0.5px,-0.5py]
        - ref: leftmain_middle_bottom
          shift: [0px,-0.5py]
        - ref: leftmain_ring_bottom
          shift: [0.5px,-0.5py]
        - ref: leftmain_pinky_bottom
          shift: [0.5px,-0.5py]
        - ref: leftmain_pinky_bottom
          shift: [-0.5px,-0.5py]
      fillet: 5
  board_right: 
    - what: polygon
      operation: stack
      points: 
        - ref: mirror_leftmain_pinky_top
          shift: [-0.5px,0.5py]
        - ref: mirror_leftmain_ring_top
          shift: [-0.5px,0.5py]
        - ref: mirror_leftmain_middle_top
          shift: [-0.5px,0.5py]
        - ref: mirror_leftmain_middle_top
          shift: [0.5px,0.5py]
        #- ref: mirror_leftmain_index_top
        #  shift: [0.5px,0.5py]
        - ref: mirror_leftmain_indexfar_top
          shift: [0.5px + 21,0.5py]
        - ref: mirror_leftmain_indexfar_top
          shift: [0.5px + 20,0.5py-36]
        - ref: mirror_leftthumbfar_in
          shift: [0.15px,0.5py]
        - ref: mirror_leftthumbfar_out
          shift: [-0.5px,0.5py]
        - ref: mirror_leftthumbfar_out
          shift: [0.5px,0.5py]
        - ref: mirror_leftthumb_out_thumb
          shift: [0.5px,0.5py]
        - ref: mirror_leftthumb_out_thumb
          shift: [0.5px,-0.5py]
        #- ref: mirror_leftthumb_out_thumb
        #  shift: [-0.5px,-0.5py]
        - ref: mirror_leftthumb_home_thumb
          shift: [0.5px-1,-0.5py]
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

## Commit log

2025-07-05 first ergogen
    [demo.dxf]
2025-07-05 choc spacing:
    [demo.dxf, raw.dxf]
2025-07-06 boards complete
    [board_full.dxf, board_left.dxf, board_right.dxf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]
2025-07-06 main pcb layout
    [banana_split.kicad_pcb, board_full.dxf, board_left.dxf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]
2025-07-06 net names for left
    [banana_split.kicad_pcb]
2025-07-06 fix net names
    [banana_split.kicad_pcb]
2025-07-06 remove reversibility
    [banana_split.kicad_pcb]
2025-07-07 pcb routed
    [banana_split.kicad_pcb, routed_banana_split.kicad_pcb]
2025-07-07 creat BOM.xlsx
    [BOM.xlsx]
2025-07-07 render 1
    [BOM.xlsx, Kailh_Choc_Low_Profile_Switch.step, reset.step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]
2025-07-07 Added case
    [BOM.xlsx, Case-Left.3mf, Case-Right.3mf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]
2025-07-07 finishing up
    [BOM.csv, BOM.xlsx, keycap.3mf]
2025-07-07 cad files
    [case_cad_file.x_t, keycap_cad_file.x_t]
2025-07-07 update render
    [keycap.step, routed_banana_split.kicad_pcb]
